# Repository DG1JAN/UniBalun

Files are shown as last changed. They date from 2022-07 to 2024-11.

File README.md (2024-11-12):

# UniBalun
a PCB for a lightweight qrp (maximum 10W SSB & CW or 5W on FT8) 1:49 UnUn (also 1:9,1:64,... possible) or Balun (1:1, 1:4)

Update to Rev. 1.2 with some minor changes (bigger Pads for the Capaciator and updated labeling)

German speaking Hams will now find a new PDF with build instructions (Bauanleitung) in the repo: https://github.com/DG1JAN/UniBalun/blob/main/Bauanleitung_UniBalun.pdf

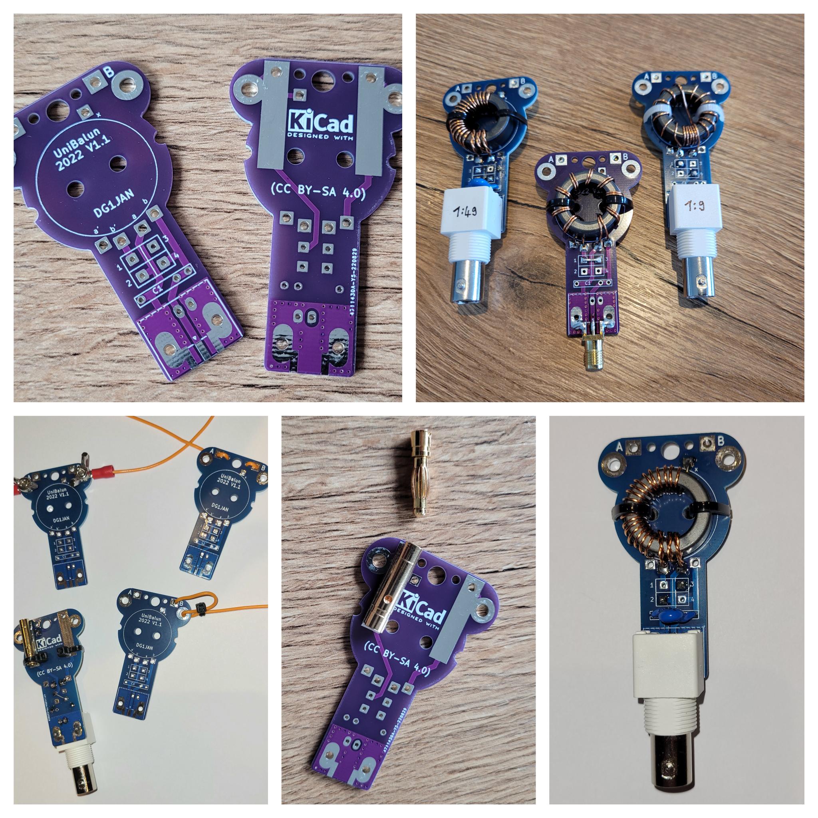
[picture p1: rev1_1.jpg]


Depending on the winding of the toroid, you can use the PCB to create a 1:1 or 1:4 Balun or a 1:49 UnUn.

1:1 Balun: solder a wire jumper between Pad 1 and 3. No capacitor.

1:4 Balun: solder a wire jumper between Pad 1 and 2 and another jumper between Pad 3 and 4. No capacitor.

1:49 Unun: solder a wire-jumper between Pad 1 and 4 on the backside of the PCB (gives better isolation). Solder the capaciator to C1

1:9 Unun: solder a wire-jumper between Pad 1 and 4 on the backside of the PCB (gives better isolation). Solder a Wire on the backside of the PCB between the a' Pad and the GND of the BNC-Plug.

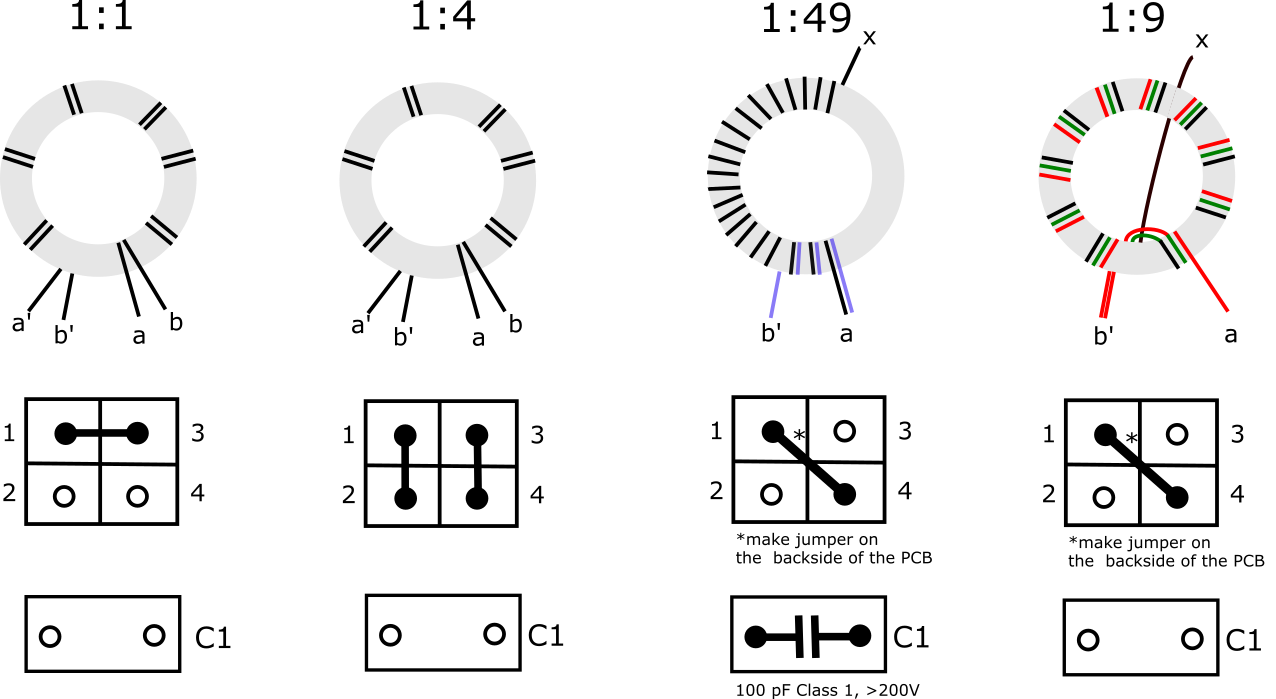
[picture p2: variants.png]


I recommend using "Amidon FT82-43" or "Fair-Rite 5943000601" (100% identical to the Amidon) Cores or the "Würth 74270118" core. The Würth core is a bit better on higer Bands, but should not be used below ~6MHz.

PRO-TIP: For lowest losses, use a FT82-43 with a FT50-43 placed inside the FT82. (they fit nicely together) A Fair-Rite 5943000601 & 5943001101 have even a better match!

Measurements have shown that the best winding radio for 1:49 UnUns on the small FT82-43 sized core is 3-to-21. 

The new revision (>1.1) has a combined footprint for BNC and SMA connectors, so only one version of the PCB is needed (thanks to DL2MAN for the idea).
For BNC connection you can use the Part: Amphenol B6252H7 / Telegärtner J01001A0038 (or similar) <br>
For SMA connection pls use a straight edge mount SMA connector (found some cheap sources at amazon, e.g. : https://www.amazon.de/10-polig-SMA-Buchse-Leiterplattenmontage-Adapter-HF-Steckverbinder-Messing/dp/B07QG2Y9L6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 )

I add two new PADs in revision 1.1 to solder 4mm ("Bana Connector") sockets directly to the PCB. I used this parts: https://www.amazon.de/gp/product/B07VYSN74H/ref=ppx_yo_dt_b_asin_title_o01_s00?ie=UTF8&th=1 

For German or EU-based OM's, I can recommend https://aisler.net/ for PCB manufacturing. You can upload the Kicad file and order the PCBs.<br>
I also have good experience with http://JLCPCB.com from China. You can upload the Gerber Files (as Zip-File) directly to their homepage. delivery time to Germany is ~10 to 14 days.
Manuel (DL2MAN) did a short How-To-Order here on Youtube: https://www.youtube.com/watch?v=1b3oLp7s9gk&t=5s

Pictures from a  1:49 UnUn build:
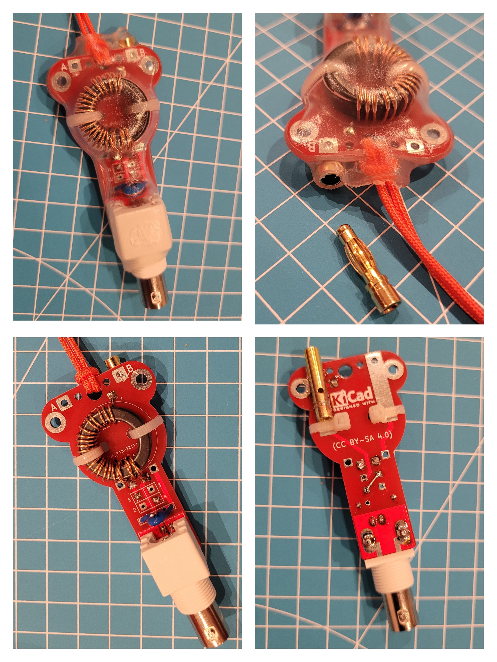
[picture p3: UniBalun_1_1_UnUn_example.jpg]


Pictures from a  1:9 UnUn build:


Here are some YouTube Videos related to the Project:

https://youtu.be/JOxsU2A5xWw?si=09692yh69wdoD_nu

https://youtu.be/WJNUpXuDDTQ?si=r2ZIQGWQCxN_N85m

https://youtu.be/oUK1LmV6amc?si=wLx39TDfT2uAble6

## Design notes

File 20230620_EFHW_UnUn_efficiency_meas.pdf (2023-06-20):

## Comparing the efficiency of Ferrite Toroids for EFHW-Antennas

### DG1JAN, 16. June 2023

Most UnUn’s used for amateur radio End-Fed-Half-Wave (EFHW) Antennas are built on the well know Amidon 43-Material ferrite toroids. Depending on the desired power level these are usually FT50-43, FT82-43, or FT114-43 for QRP or FT140-43, FT240-43 for QRO.

I also build my (qrp) Antennas around Amidon FT82-43 and FT114-43 sized cores without questing too much about the performance of the cores in the past. E.g., my UniBalun project (http://github.com/DG1JAN/Unibalun) is built based on FT82-sized cores.

But after some YouTube Videos from Manuel DL2MAN and Colin MM0OPX, I got curious about the core losses from these “standard” toroids. Colin did measurements with alternative 43-Material ferrite cores and come up with two suggestions for QRP (FairRite 2643625002) and “100W QRO ” (Fair-Rite 2643651002) that are superior to the usual ones.

Already some time ago, I was playing with a “stacked” FT-82-43 / FT50-43 combination. (The FT50 fits nicely inside the FT-82) Unfortunately, I haven’t done any performance measurements till now.

As (IMHO) Amidon toroids are “just” relabeled Fair Ride products (but please enlighten me, if you have detailed information about the relation between Fai Rite and Amidon), I used Fair-Rite products for my tests, as they are available and much Cheaper to source from Digikey as the same cores from Amidon here in Germany.

For the “stacked” FT82/FT50 there is (size-wise) even a better match with the Fair Rite 59430000601 and 5943001101.

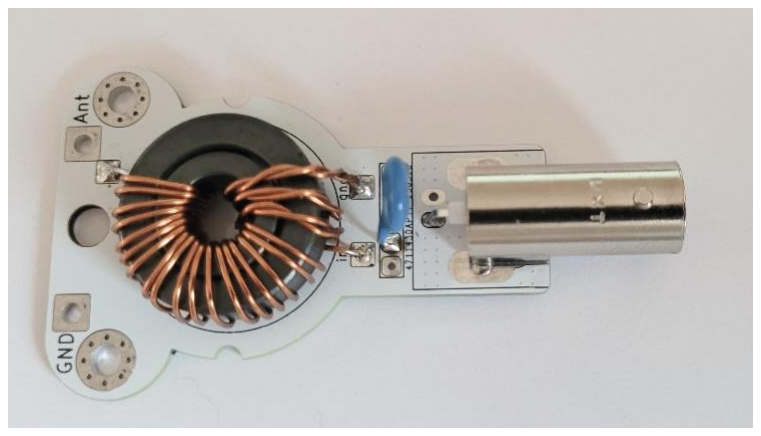
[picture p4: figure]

So, I decide to make some measurements to compare different cores. To have a reference I also include the “QRO” core from MM0OPX .

Instead of doing the Back-to-Back measurements with two “identical” toroids, I decide to go with a measurement setup that uses a load resistor (2400 Ohm – for the 1:49 UnUns). This should lead to better results compared to Back-2-Back, as the flux levels in the two cores are not equal and the losses are not “linear” over the two cores. AI6XG did a nice documentation of his measurements, which at I used as a source.

Following toroids/combinations I have tested:

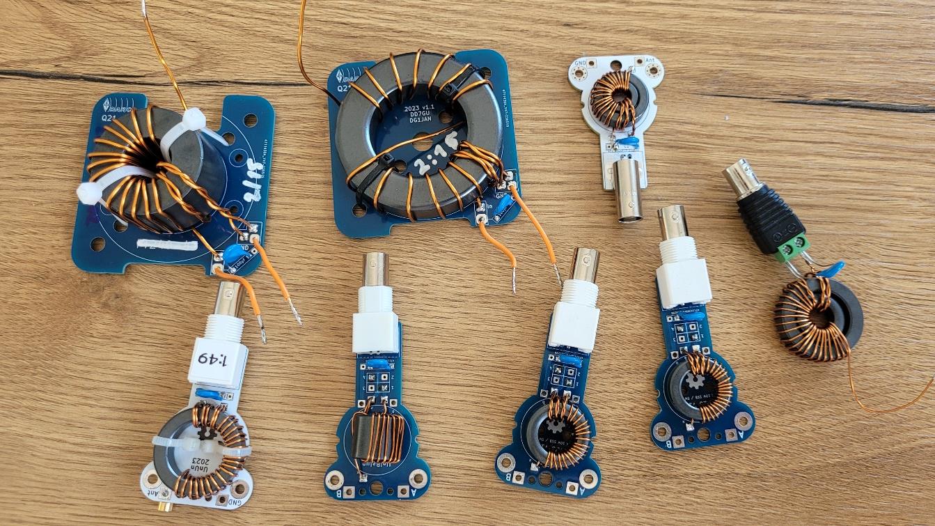
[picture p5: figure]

### Results

For the QRP variants, it could be shown, that the FT82 and FT114-sized cores have average losses of around 20% (80% efficiency). The “stacked” variants (esp. 59430000601 + 5943001101) showed a superior efficiency of around 10% (efficiency across all HF Bands from around 90%). A similar result can be seen for the toroid suggested by MM0OPX (2643625002).

For the “100W” variant the 2643251002 shows even a bigger improvement to the FT240-43. On average the is a 15% higher efficiency. Thanks to Colin for this suggestion!

In the end, it could be discussed, if an improvement in core losses of 10% to 15% makes a real difference in the performance of an EFHW antenna (compare to 6dB per S-Step). But especially for digital modes with typical high-duty cycles, there is (IMHO) a benefit by reducing the core heating due to higher efficiency.

Besides the measured transformer losses here, there are also other losses to consider. E.g. the saturation effects at high flux and especially the temperature-related changes in permeability.

FairRite 2643803802 (FT240-43), 2/15, 100pF FairRite 2643251002 (MM0OPX), 2/15, 100pF FairRite 59430000601 (FT82-43), 3/21, 100pF FairRite 59430000601 + 5943001101, 3/21, 100pF FairRite 5943000501 ("double" FT82-43"), 3/21, 100pF FairRite 2643625002 (MM0OPX), 2/16, 100pF FairRite 5943001001 (FT114-43), 3/21, 100pF FairRite 5943001001 + 2643665902, 3/21, 100pF Amidon FT140-43 , 2/14, 100pF

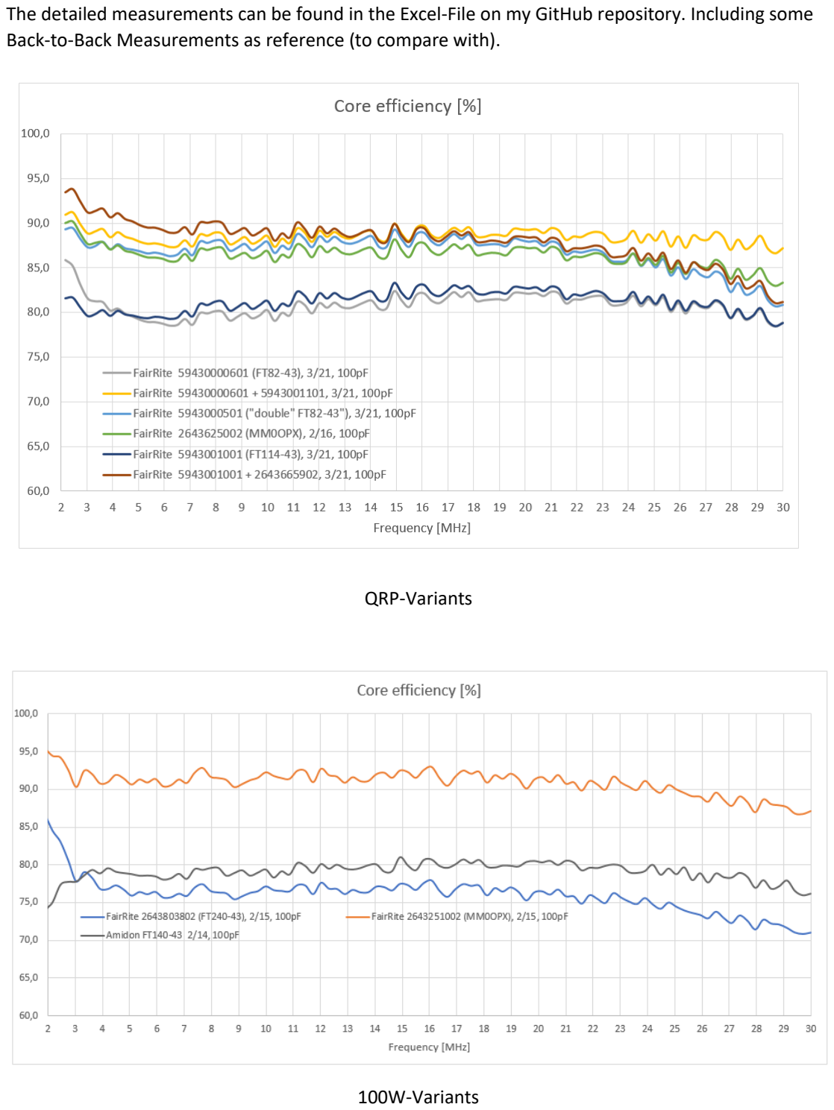
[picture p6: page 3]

The detailed measurements can be found in the Excel-File on my GitHub repository. Including some Back-to-Back Measurements as reference (to compare with).

QRP-Variants

100W-Variants

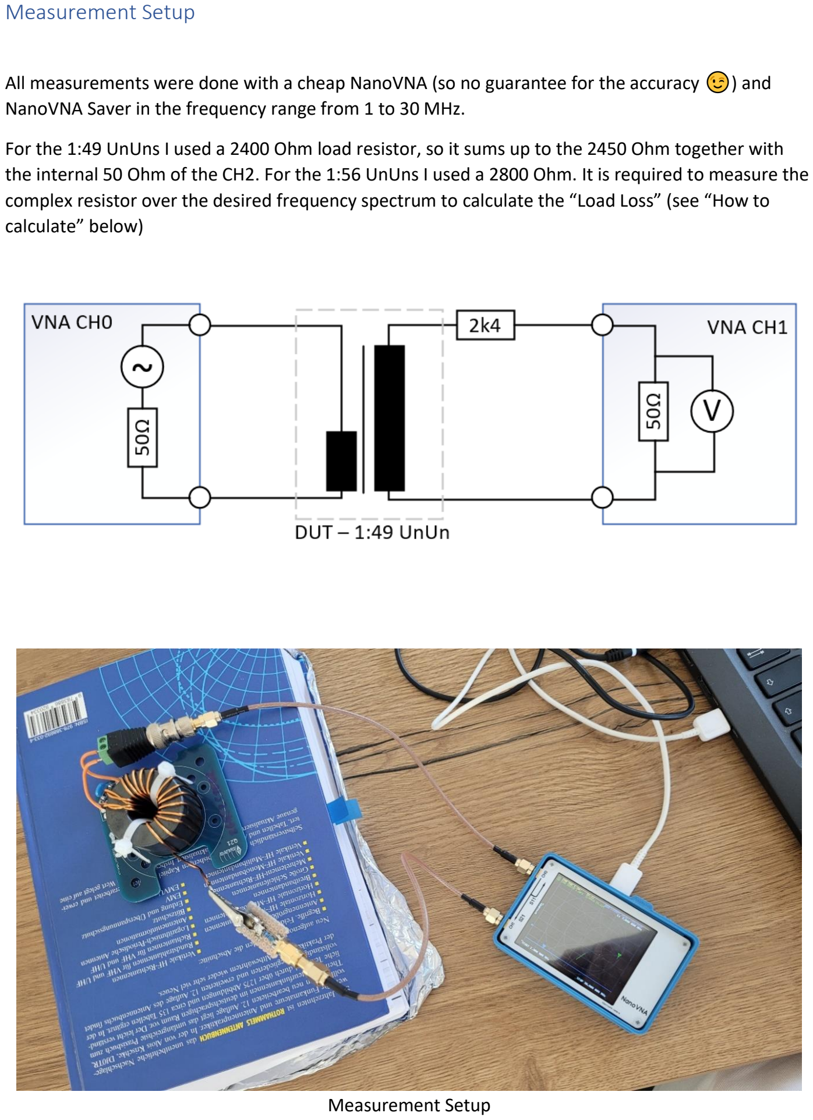
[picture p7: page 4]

### Measurement Setup

All measurements were done with a cheap NanoVNA (so no guarantee for the accuracy ) and NanoVNA Saver in the frequency range from 1 to 30 MHz.

For the 1:49 UnUns I used a 2400 Ohm load resistor, so it sums up to the 2450 Ohm together with the internal 50 Ohm of the CH2. For the 1:56 UnUns I used a 2800 Ohm. It is required to measure the complex resistor over the desired frequency spectrum to calculate the “Load Loss” (see “How to calculate” below)

Measurement Setup

### How to calculate

The total insertion loss of the transformer is calculated by the measured S21 Parameter:

Insertion_Loss[dB] = -20 * log( |21| )

As S21 is a complex value, NanoVNA gives you (in the s2p-file) a real and imaginary part, so you can calculate:

Insertion_Loss[dB] = -20 * log( sqrt ( S21real^2 + S21imag^2 ) )

This Insertion loss is the sum of the Mismatch Loss, the Transformer Loss and the Load Loss (in the Load Resistor). So, we can calculate the core loss by:

Transformer_Loss [dB] = Insertion_Loss[dB] - Mismatch_Loss [dB] – Load_Loss [dB]

The Mismatch Loss is coming from the difference in Impedance on the primary site of the transformer compared to the CH0 Port of the NaoVNA (50Ω+j0 Ω) and calculated from the complex S11 value (given in the s2p-file)

Mismatch_Loss [dB] = 10 * log( 1 - |S11|^2)

With |S11| = sqrt ( S11real^2 + S11imag^2)

As we were required to add a real “Load Resistor” (with capacitive and inductive effects) to match the impedance, we need to measure and calculate the Loss Load. This is done by a series through measurement of the resistor only.

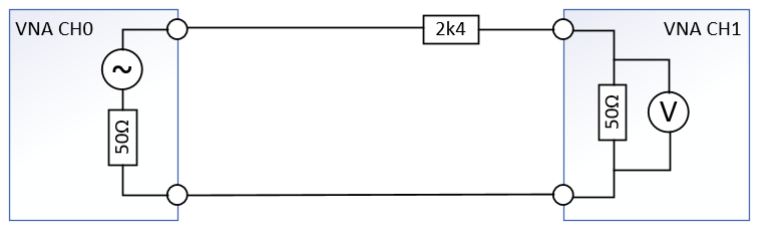
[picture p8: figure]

Load_Loss[dB] = 10 * log ( |S21|^2 / (1-|S11|^2) ))

With |S21| = sqrt ( S21real^2 + S21imag^2) and |S11| = sqrt ( S11real^2 + S11imag^2)

Now we have everything together to calculate the Transformer Loss and the Power Efficiency of the core. (But keep in mind that this is not covering additional losses in practical (esp. QRO) operation with high flux and heating)

Power_Efficency[%] =100 * 10 ^( Transformer_Loss[dB]/10)

BTW: you can also calculate VSWR from the s2p-data:

VSWR = (1 +|S11|) / (1-|S11|)

But please be aware that VSWR is only an indicator, as real EFHW Antennas usually don’t have a perfect real 2450Ω resistance in the resonance points

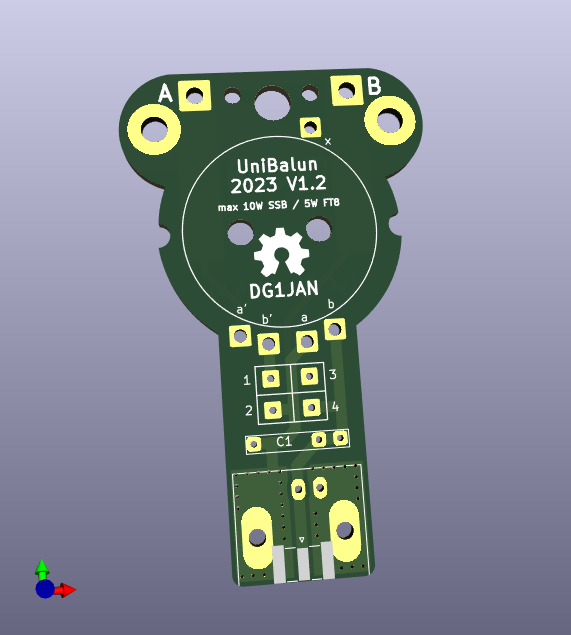
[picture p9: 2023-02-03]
Uni_Balun/UniBalun1.2_3D_Pic1.png

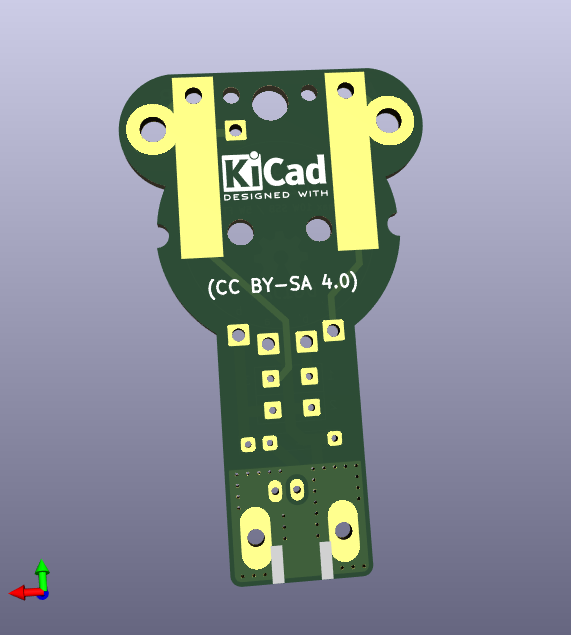
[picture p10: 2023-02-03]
Uni_Balun/UniBalun1.2_3D_Pic2.png

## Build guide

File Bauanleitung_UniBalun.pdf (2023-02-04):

# UniBalun Bauanleitung

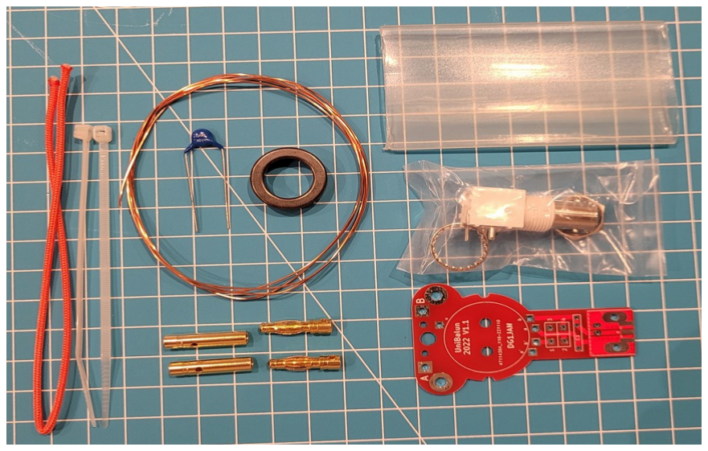
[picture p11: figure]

Materialliste/ BOM

1x Ringkern Amidon FT82-43 oder Fair Rite 5943000601
1x Keramik Kondensator 100pf/1kV
1x Platine UniBalun
1x BNC oder SMA Buchse
1m Kupferlackdraht 0,63mm (oder ähnlich) 2x 4mm Buchse (bei Bedarf)
2x 4mm Stecker (bei Bedarf)
2x Kabelbinder
1x Paracord (bei Bedarf)
1x Schrumpfschlauch 32mm breit (ggf mit Kleber)

Sicherheitshinweis
Diese Bauanleitung richtet sich an lizenzierte Funkamateure, die entsprechend Ihrer Qualifikation über die Gefahren von elektrischem Strom unterrichtet sind, diese einschätzen und einen sicheren Betrieb gewährleisten können.
Die Antenne ist lediglich zur temporären Nutzung bei trockener Witterung (Portabel-Funkbetrieb)
ausgelegt. Maximale Leistung 10W SSB sowie CW bzw. 5W bei FT8 oder ähnlichen Betriebsarten.
Bei Antennen können (auch schon bei geringer Sendeleistungen) hohe HF-Spannungen entstehen. Entsprechende Schutzabstände sowie ein Berührungsschutz sind einzuhalten.
Haftungsausschluss
Es wird vom Ersteller dieser Anleitung keinerlei Haftung für Schäden an Geräten oder Personenschäden übernommen! Weitergehende Ansprüche sind ausgeschlossen.

Für Schäden, die direkt, indirekt oder Folgeschäden, die aus dem Nachbau resultieren, wird keinerlei Haftung übernommen. Dies gilt gleichsam für Schäden, welche durch bestimmungsfremde Nutzung entstehen.

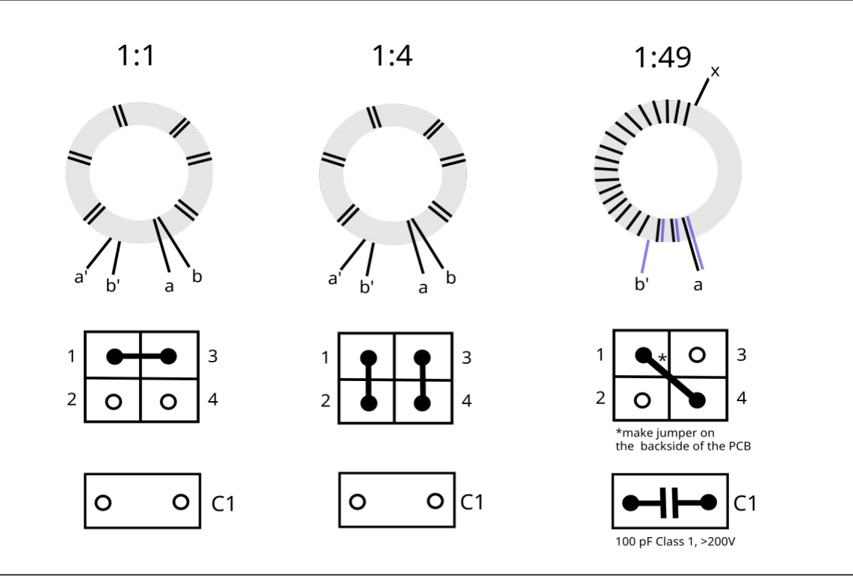
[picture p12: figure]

### Bild 1

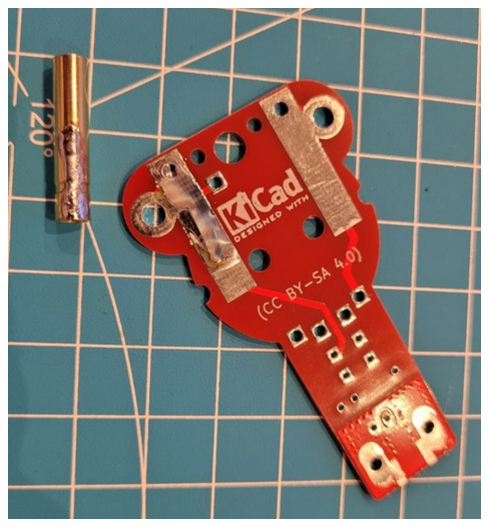
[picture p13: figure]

1) Falls der Anschluss über die 4mm Bananenbuchsen gewünscht ist, sollten diese als erstes aufgelötet werden.

Es kann sinnvoll sein die Buchsen auf der Platine 5mm über den Rand überstehen zu lassen. Damit kann dann ggf. später der Schrumpfschlauch besser abdichten.

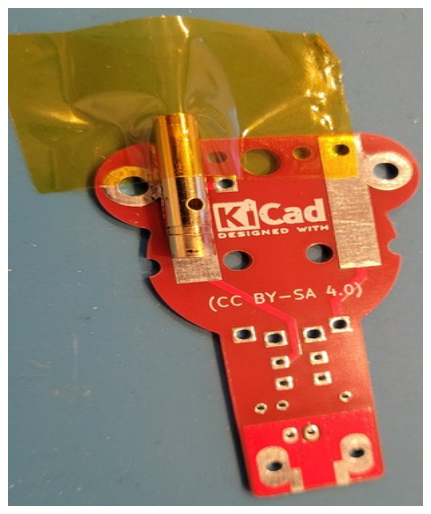
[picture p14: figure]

1.a) Für eine 1:49 EFHW nur die Buchse an Seite B anlöten.

Tipp: Am besten lassen sich die Buchsen mit einem Heißluftlötkolben und SMD-Lötpaste auflöten. Alternativ kann man auch die Bauteile Vorverzinnen und mit Kapton-Tape oder einer Zange/Pinzette beim Auflöten fixieren.

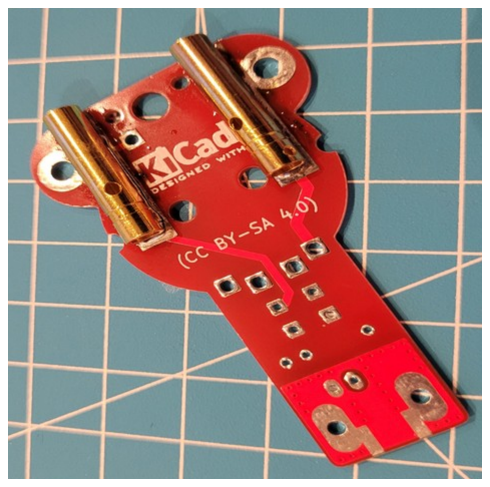
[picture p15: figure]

1.b) Für eine Dipol Konfiguration (1:1, 1:4) beide Buchsen anlöten, sofern keine andere Befestigungsart gewählt wird.

2) Wickeln des Ringkerns

Wickelschema nach Bild 1:

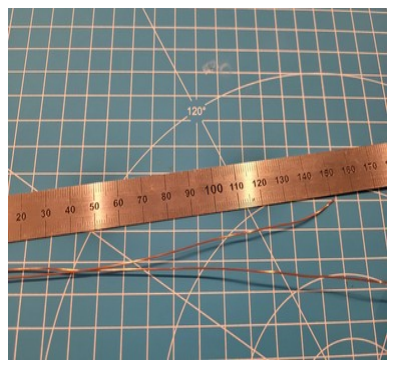
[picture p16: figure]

2.a) Für einen 1:49 UnUn den Kupferlackdraht an einem Ende um etwa 15 cm nach hinten biegen und die zwei Drähte dann leicht verzwirbeln.

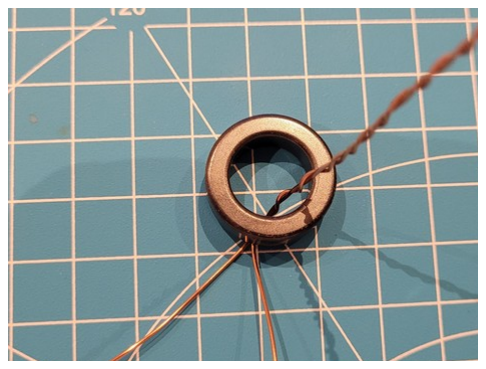
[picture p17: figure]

Von der Mitte an zuerst die Primärwicklung (nach rechts) wickeln.

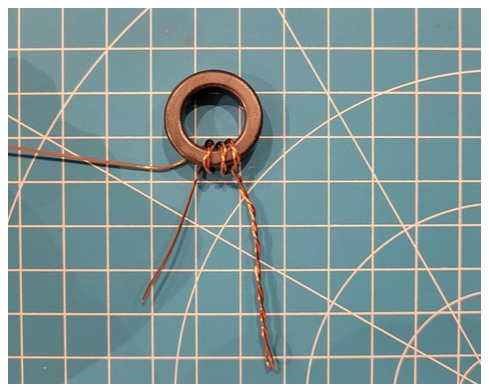
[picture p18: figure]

Mit den verzwirbelten Drähten müssen drei Wicklungen ausgeführt werden.

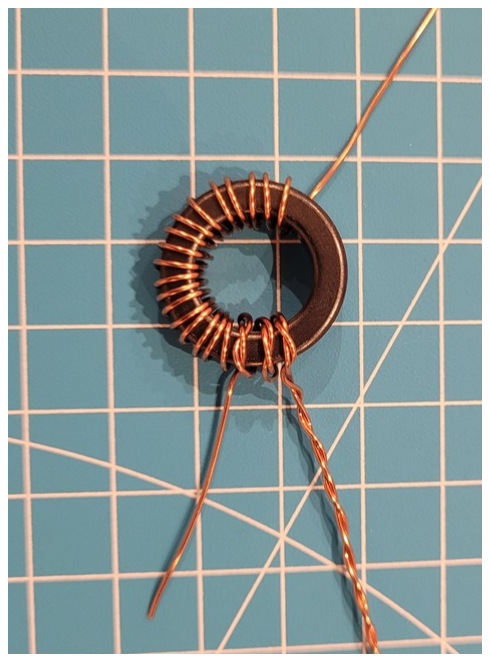
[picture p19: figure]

Danach mit dem langen Drahtende weitere 18 Windungen nach links wickeln. Das Windungsverhältnis ist damit insgesamt 3-zu-21, welches einer Impedanztransformation von 1:49 entspricht.

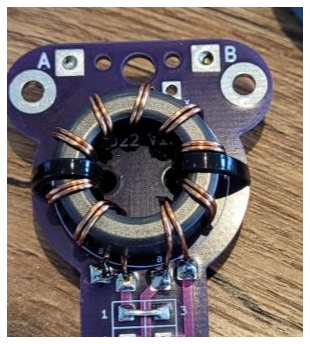
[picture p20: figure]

2.a) Für einen 1:1 oder 1:4 Balun den Kupferdraht halbieren und 9 (oder mehr) Bifilar-Windungen wickelt. Dabei darauf achten, dass sich die Drähte nicht überkreuzen und Parallel aneinander liegen.

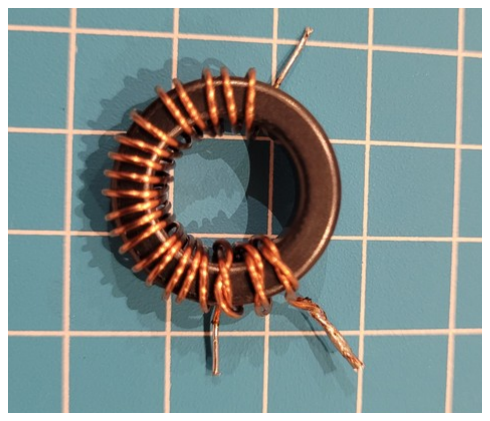
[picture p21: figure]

3) Die Enden des Kupferlackdrahts jeweils auf etwa 1,5cm einkürzen und verzinnen. Tipp: zuvor den Schutzlack durch leichtes „kratzen“ (Elektronikseitenschneider, Messer, etc.) im Bereich der Lötstelle entfernen.

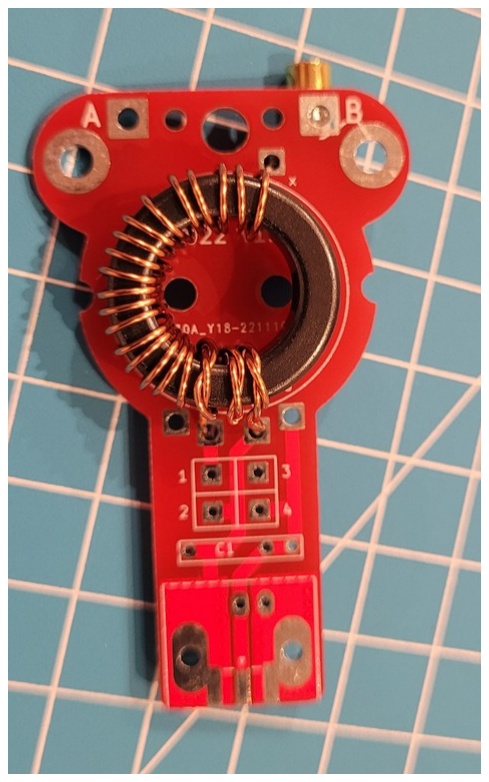
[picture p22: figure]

4) Einlöten des Ringkerns. Anschluss entsprechend Bild 1. (hier 1:49 UnUn als Beispiel) Tipp: Bei dem 1:49 UnUn unbedingt darauf achten, dass die mittleren Anschlüsse (b’ und a) genutzt werden!

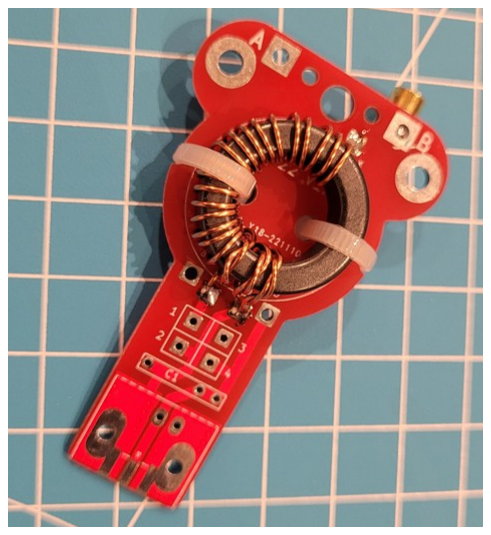
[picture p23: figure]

5) Befestigen des Ringkerns mit den zwei Kabelbindern.

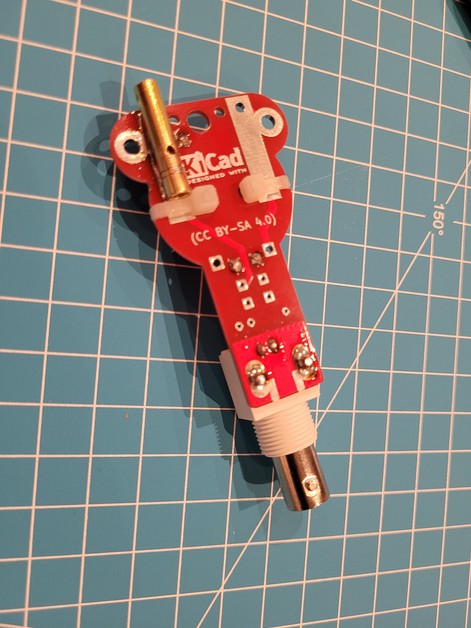
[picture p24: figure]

6) Einlöten der BNC Buchse (alternativ kann auch eine „edge-Mount“ SMA-Buchse verwendet werden.)

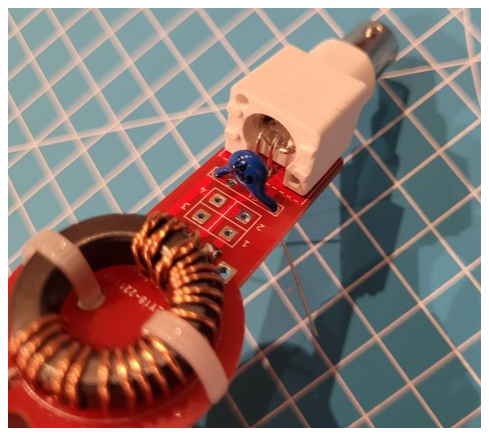
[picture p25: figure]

7) Für den 1:49 UnUn, den 100pF Kondensator einlöten.

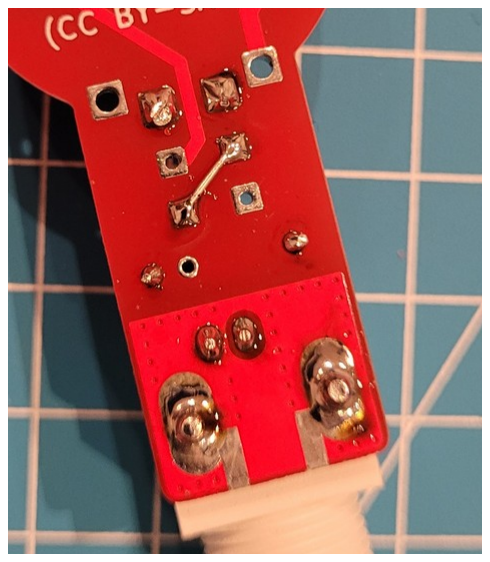
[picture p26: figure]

8) Drahtbrücke(n) nach Bild1 einlöten: 1:1 1:4 1:49 *Für den 1:49 UnUn wird empfohlen, die Drahtbrücke auf der Rückseite der Platine zu machen. (siehe Bild rechts) Hierzu können die abgeschnittenen Anschlussdrähte des Kondensators genutzt werden.

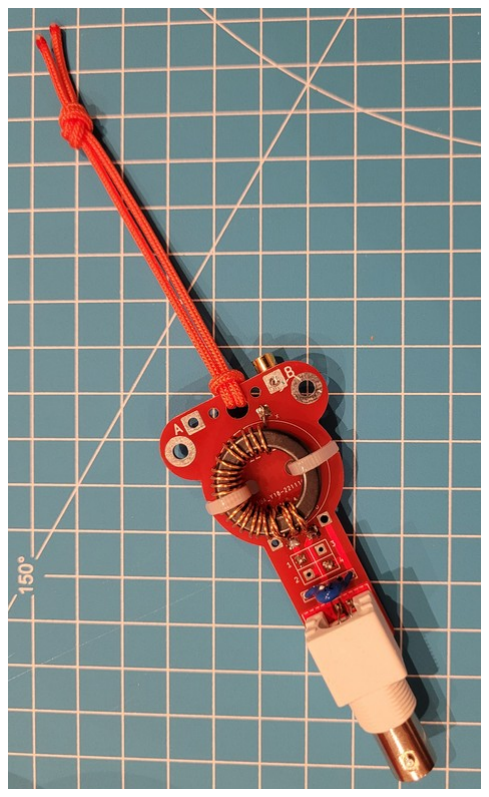
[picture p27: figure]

9) Seilschlaufe (sofern gewünscht) befestigen

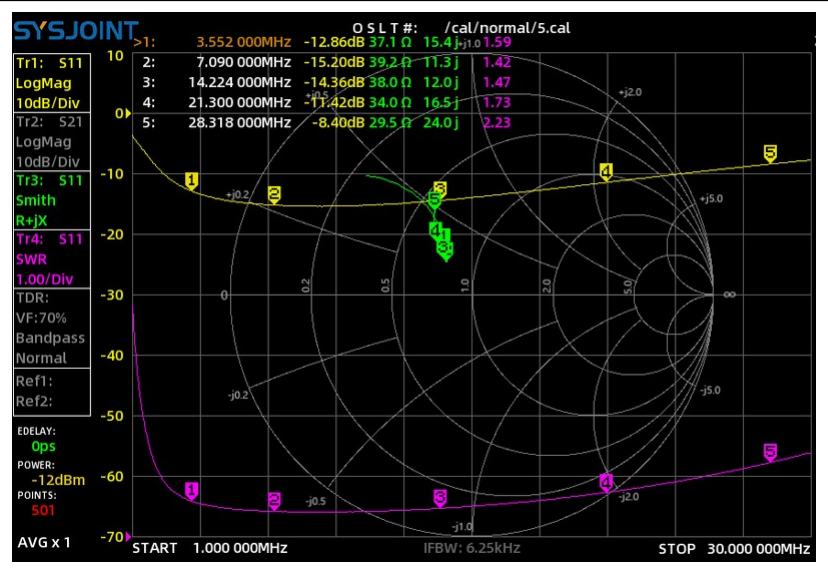
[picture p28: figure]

10) Funktionsprüfung durchführen.

Tip: Idealerweise mit einem VNA den Balun/UnUn auf Funktion prüfen. Dazu die Antennenseite mit entsprechendem Widerstand abschließen und VSWR bzw. S11 messen.

(Beispiel für einen 1:49 UnUn mit 2450Ohm Abschlusswiderstand an einem VNA im Bild rechts)

Abschlusswiderstand:
- für 1:49 UnUn → 2450 Ohm von Anschluss B nach Masse
- für 1:1 Balun → 50 Ohm von Anschluss A zu Anschluss B
- für 1:4 Balun → 200 Ohm von Anschluss A zu Anschluss B

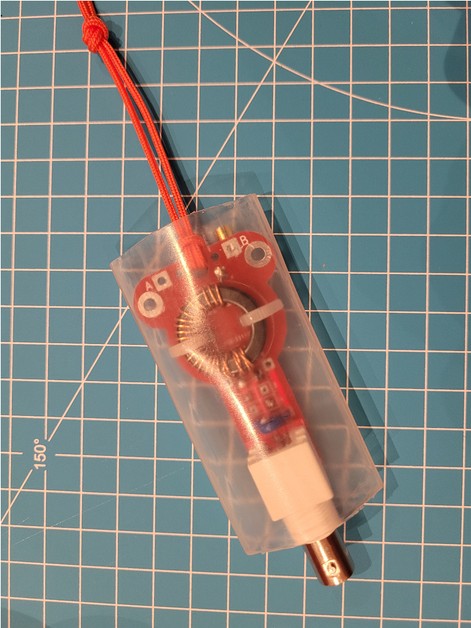
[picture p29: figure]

10) Nach erfolgreicher Funktionsprüfung (bei Bedarf) die Platine mit Schrumpfschlauch einschweißen.

### Wenn der Schrumpfschlauch mit einer Klebeschicht versehen ist, lässt dieser sich nach dem Verschweißen so gut wie nicht mehr entfernen !!!

Tipp: Den Schrumpfschlauch an der oberen Seite (bei den Antennenanschlüssen) ein wenig überstehen lassen. Im heißen Zustand kann das Ende dann zusammengedrückt werden und der Kleber schließt alles Wasserdicht ab. Mit einem Messer oder Elektronikseitenschneider können die 4mm Bananenbuchsen nach dem Auskühlen dann wieder freigelegt werden.

9) Befestigen des Antennendrahts nach Wahl ;-)

### Viel Spaß und Erfolg beim Nachbau!

### 55 & 73 de Jan, DG1JAN

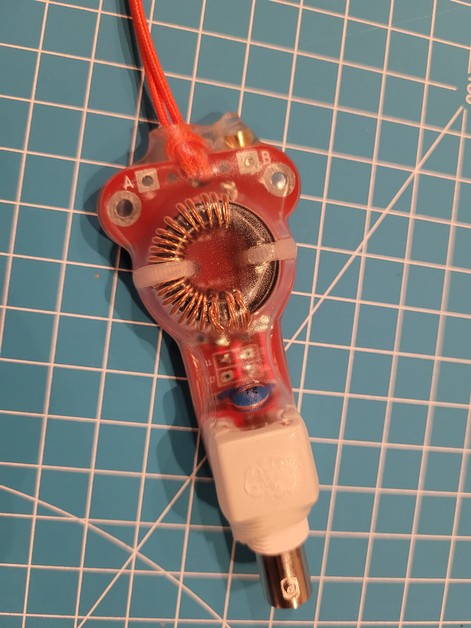
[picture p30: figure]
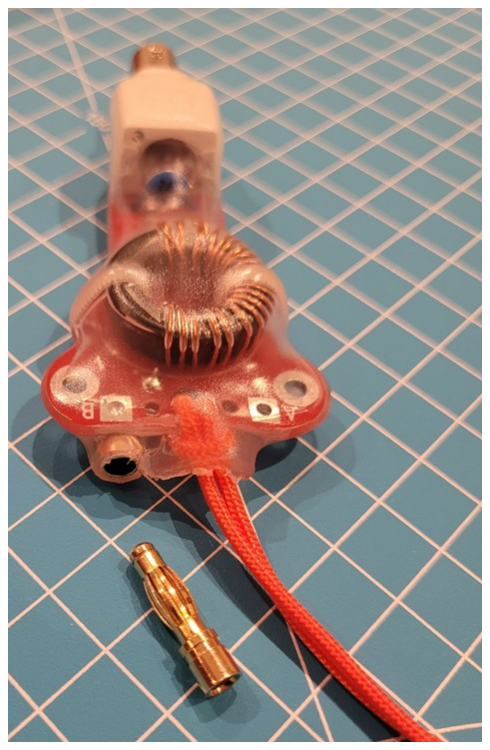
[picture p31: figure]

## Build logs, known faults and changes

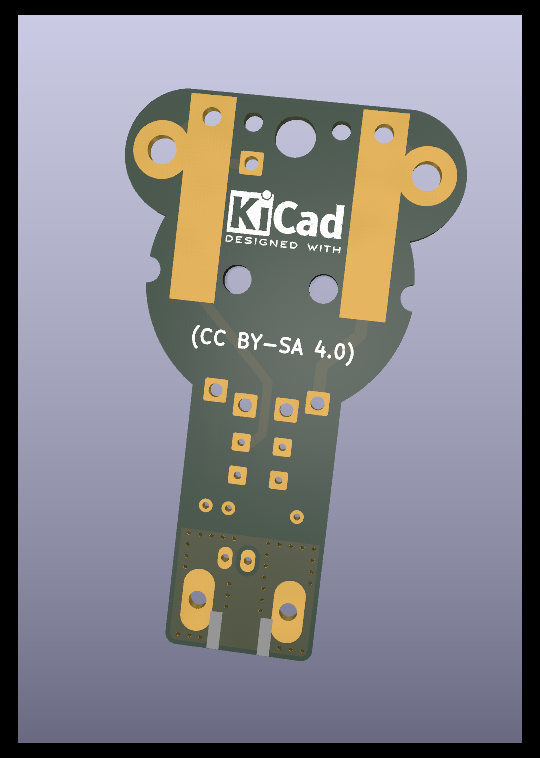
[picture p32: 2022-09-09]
history/UniBalun_1.1/pic_3d_back.png

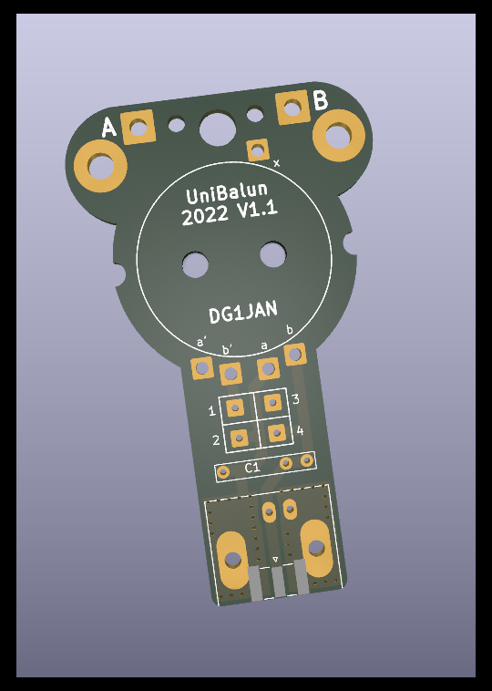
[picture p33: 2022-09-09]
history/UniBalun_1.1/pic_3d_front.png

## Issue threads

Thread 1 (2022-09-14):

BNC male plug version

dl1hbt, 2022-09-14:
Jan, I am a big fan of less cable whereever possible. Do you think it might be possible to change the PCB design to be able to use a BNC male plug 90 deg angle as well? I have found this one on amazon: https://amzn.eu/d/83ZCG39 but did not order any by now. Maybe it fits without the need to change the PCB design...vy73/55, Tom (DL1HBT)

dl1hbt, 2022-09-16:
Hi Jan, I have ordered five BNC plugs for PCB installation via amazon. I expect them to arrive from China within the next two weeks. I will check the footage and give feedback on whether it works with or without the need to edit the PCB design. vy73/55, Tom

dl1hbt, 2022-09-16:
Jan, that´s perfect...thanks for your actions taken. My address is up-to-date, I am looking forward to receiving the PCB and will reply as soon as I have received the BNC plugs from China. Thanks also for your hint oncerning the necessity for a counterpoise! vy73/55, Tom

dl1hbt, 2022-09-17:
Jan, PCB v1.1 arrived today...thanks!

dl1hbt, 2022-09-23:
Jan, received the BY-BNC 90 deg angle plug for PCB mountage yesterday. I will send you one sample, prbably you might want to check, if the PCB design can be modified easily and a mount point for a counterpoise can be marked on the board. vy73/55, Tom

DG1JAN, 2022-09-23:
Hi Tom, thanks. I will have a look and will do a  "special" version that support your connector. In this case I think it makes sense to remove the posibillity for BalUn usage of the PCB (as it will be attached to radio directlý, the Dipol configuration will make no sense anyhow.
Then I can use the "A" antenna connector for GND/Counterpoise and "B" will be for the Antenna.

dl1hbt, 2022-09-25:
Hi Jan, yes...maybe it is clever to seperate the PCBs capability to handle Balun _and_ UnUn...
Back from SOTA in DM/TH and DM/HE, Tom

DG1JAN, 2022-09-28:
Thanks Tom,

part has arrived :-) The Footprint is not compatible with the SMA-connector, so I made a new Version (only 1:49) with your Part.
All Files (KiCad and  Gerber) can be found here: https://github.com/DG1JAN/AntennaPlayground/tree/main/DL1HBT_UnUn

Closed 2022-09-28.

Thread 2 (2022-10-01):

1:49 Capacitor?

Mkpowell2, 2022-10-01:
I apologize if I missed it, but could you please clarify which capacitor you recommend for the 1:49 version? I am trying to build this amazing project but don't know which capacitor to use.

A part number would be awesome if you have one handy as I am not familiar with electrical engineering. Thank you!

Myles

DG1JAN, 2022-10-02:
Hello Myles,

thanks a lot for the nice words and your question.
You can use any 100pF Ceramic or Silver Mica capacitor that has a voltage rating >200V (even 100V would be Ok for qrp, but I like to have some margin).

I don't know, where you from, and what distributor you prefer.
Here are some sources as example:
https://www.reichelt.de/it/de/keramik-kondensator-100-pf-3-kv-85-c-vis-hcz101kbcdf0-p247584.html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

https://www.digikey.de/de/products/detail/tubedepot/CP-SM-100-500V/10489633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

you can also have look on Amazon. search for "100pf silver mica capacitor"

Regarding the shrink tube, you can use any product, that is wider than 40mm. can be found e.g. on Amazon as well.

BR, vy 73
Jan

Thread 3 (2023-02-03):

Aisler.net shows warning on shortened pads

db6edr, 2023-02-03:
Hi Jan,

I've just uploaded the UnUn_BNC/UnUn_BNC.kicad_pcb to Aisler.net. Their board inspector gives a remark on some shortened pads. As I'm not used to creating / fabricating PCBs: is that as expected? Or does this require fixing?

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

73 de Dirk DB6EDR

DG1JAN, 2023-02-03:
Hello Dirk,

Thanks for the hint! This is a non functional issue, due to my manual editing of the PCB (out of the UniBalun File).
Didn't checked it, because I ordered at JLCPB using gerber files.

I have updated the Net classes in the pcb file, so the Error from Aisler.net should be gone.

73 de Jan, DG1JAN

db6edr, 2023-02-03:
Just checked, the error is gone.

Thanks!

Closed 2023-02-03.

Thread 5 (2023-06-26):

Query re efficency spreadsheet - FairRite 5943000601 + 5943001101

virtual812, 2023-06-26:
If I understand correctly you've found some significant efficiency with this combo.

I'm looking to replicate your results, it would seem you had the smaller toroid sitting inside the larger one, is this correct?
Would this also marginally increase power handling? say 20W SSB / 10W FT8?

Have you any advice for size of copper wire?
Sounds in theory that things might get tight inside the 7.9mm ID of the smaller toroid.

Also any thoughts on good cores for 1:1 and 4:1 baluns running ~ 80M to 10M bands?

DG1JAN, 2023-06-27:
yes, I think the combination of the FairRite 5943000601 + 5943001101 (or Amidon FT82-43 + FT50-43) will bring a slightly improvement in efficiency according my measurements. I would really appreciate if you (or other OMs) could validate this.

Do to the lower core losses and a bit higher mass of the combined toroids, I guess also the power handling will improve. But I haven't done any measurements yet. I only used a 1:49 with this configuration for 20W portable operation in SSB. I didn't recognize any warming (ambient temp 27°C) during this. (Of course SSB was on a very low duty cycle)

As copper wire I was using 0,63mm, as you can se in the picture in the PDF its tight, but just ok with the 3-to-21 winding.

I haven't done much testing for Baluns, yet. From the efficiency point, the core its much less critical IMHO, as only the common mode current is creating flux. For smal dipols (linked Inv-V) I have used Amidon F82-43 (or FairRite 5943000601) and Würth 74270118. But don't expect to much common mode rejection below the 20m Band with the small cores. (for 14 to 30Mhz i measured ~20 - 30 dB, but only 13dB on 40m and 7dB on 80m)

virtual812, 2023-06-30:
Thanks Jan, will have a go.
Not done a lot of building & testing before, will read up on how to test.
I think i've seen a kind of back to back test done by you and/or DL2MAN.
Weather is beginning to improve here in Australia so hopefully will be outdoors and on air soon.
QRM at home is terrible!

virtual812, 2023-07-06:
PCBs ordered, Toroids ordered, struggling to find 0.63 Enameled Copper Wire.
I have 1.0mm and 0.8mm on hand.
I can buy 0.56mm and 0.71mm
Looking at capacitors also, the PDF mentions class 1
My RF knowledge is still elementary, but I'm aware capacitor types matter.

I have some of these in 100pF...
https://www.minikits.com.au/Mica-Series

I'm also looking at buying these - Dielectric Characteristic SL...
https://au.element14.com/tdk/cc45sl3ad101jyvna/disc-capacitor-100pf-1kv-radial/dp/3651151

and / or these  - Dielectric Characteristic	C0G / NP0...
https://au.element14.com/tdk/fg28c0g2e101jnt06/cap-100pf-250v-mlcc-radial/dp/3416508

I'll collect up all the parts and read up on how to test.
My understanding is that testing works best with 2 matching units back to back on a VNA.
It's a crude instrument i think, but i have a nanoVNA that i could try.

I'm also looking at building your balun test tool.
At up to 60MHz do resistor types matter?
Looking at metal film, wire wound and ceramic.
I recall reading somewhere that some kinds of resistors add inductance, the wire wound probably and maybe the metal film?
Any thoughts on that?

I'd be happy to test and share my results.

DG1JAN, 2023-07-23:
I think 0.56mm is a good choice for the combined cores.

The Mica caps are fine. I usually use TDK  CC45SL3FD101JYVNA (e.g. from DigiKey)

For testing it is important to use low inductance resistors like metal-oxide. In general I would not recommend using my "Balun Test tool" for >30MHz. In general its better to use single resistors with very shorts leads (as short as possible).

schornhe, 2023-07-25:
To which spreadsheet are you referring. Can you please provide a link?

virtual812, 2023-07-26:
> To which spreadsheet are you referring? Can you please provide a link?

It's in the repository.
https://github.com/DG1JAN/UniBalun/blob/main/20230620_UnUn_Efficency_Meas.xlsx

virtual812, 2023-10-01:
Hi Jan, finally getting around to this.
I'm expecting the toroids to arrive any day.
Just had some questions about the testing method.
I have both a nanoVNA and a TinySA, i also have your balun test tool.
I see a rough idea about how to test here.
Is this similar to the method you used?
I'm still learning a few things.
I don't have it with me currently, but i guess there is a mode where the VNA can output a signal and measure loss on it's incoming port.
Any info you could share on how you tested would be appreciated.

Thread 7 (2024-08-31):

wiring for 9:1 unun

benmarwick, 2024-08-31:
Hi Jan,

Thank you so much for making available the plans for these very versatile boards. I am attempting to make the 9:1 unun by following the image here https://github.com/DG1JAN/UniBalun/blob/main/UniBalun_1to9_example.jpg and just want to check I have the wiring correct.

Here's the description of my wiring:
-  start of wire 1 joined to end of wire 2.
-  start of wire 2 joined to end of wire 3, both soldered to b', which goes to the coax centre pin via a bridge between 1 and 4 on the back of the PCB
- start of wire 3 soldered to a, which goes to coax shield and counterpoise attachment A, via a bridge on the back of the PCB
- end of wire 1 soldered to x, which is antenna attachment B

And here's a simple schematic:

```
w1-start -----------|
w2-start ------|    |
w3-start ------>---->----- a - coax shield & cp via bridge to a'
               |    |
               |    |
w1-end -------->---->----- x - B - antenna
w2-end -------->----|
w3-end --------|
               |
               b'
               |
          1 bridge to 4
               |
            coax pin

```

Does that look right to you?

Thank you so much,

Ben

DG1JAN, 2024-09-12:
Hello Ben,

I'm sorry its a bit hard for me to read the ASCII Schematic. Please have a look to this document
https://github.com/DG1JAN/UniBalun/blob/main/Bauanleitung_UniBalun_als_1zu9.pdf

Unfortunately I made this Instruction only in German yet, but from the pictures I guess its pretty easy to understand how I did the wiring.

best 73 de Jan

benmarwick, 2024-09-13:
Thank you for your reply, yes I was looking at this image from your PDF and found it confusing to understand what to do with ends of the wires.

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

I see red, green and black wires on the left, and the other ends of those wires on the right. But for the ends of the wires in the PDF I only see two red and one black. It is not clear what to do with the two green ends, and the other black end.

Is it the same as this diagram from [vk6ysf.com](https://vk6ysf.com/unun_9-1.htm)

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

Thank you so much

DG1JAN, 2024-09-15:
yes, its the same. sorry for confusing. maybe its also because I dont have wire "ends". I use to wound the UnUn in one turn. Means, making a tab after the first coil and then winding two more rounds. (as you can see in the photos of the pdf)

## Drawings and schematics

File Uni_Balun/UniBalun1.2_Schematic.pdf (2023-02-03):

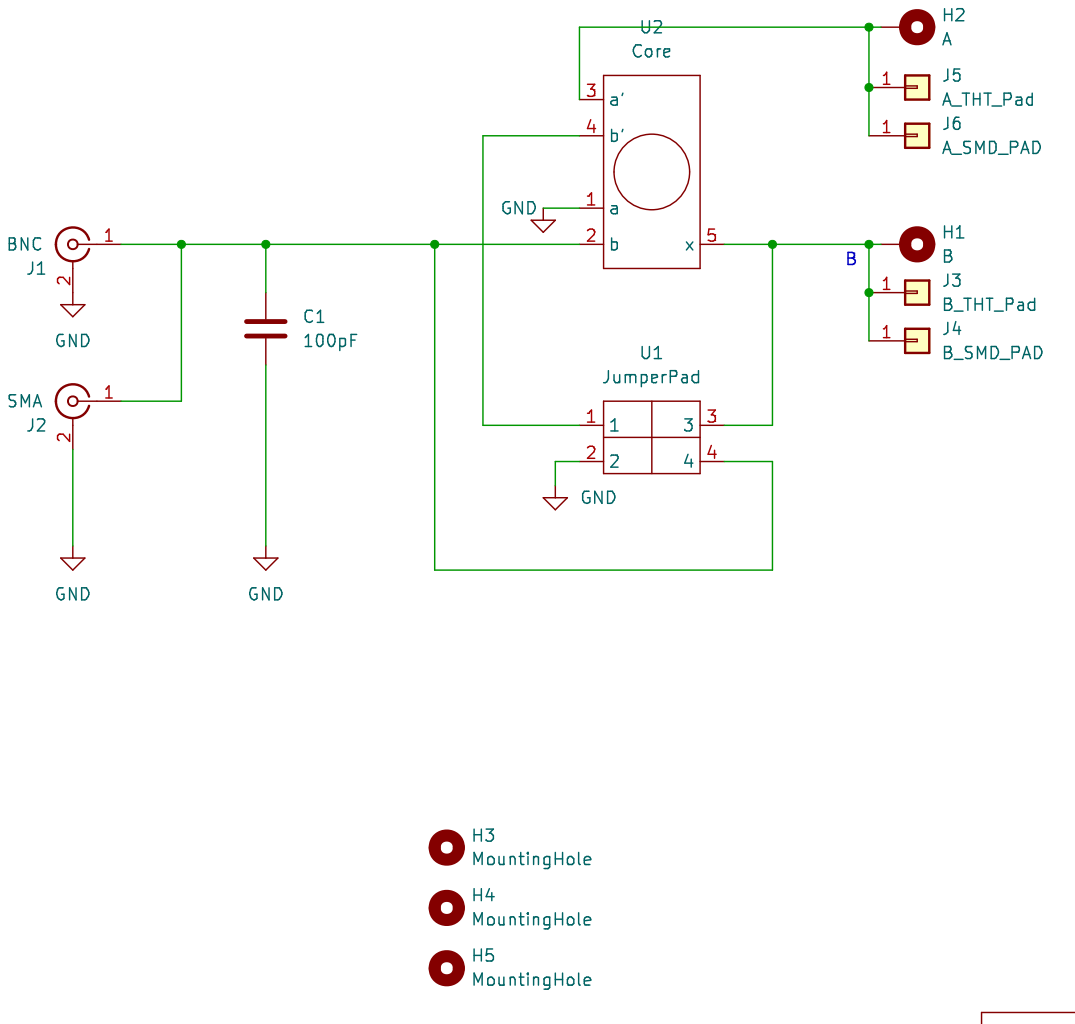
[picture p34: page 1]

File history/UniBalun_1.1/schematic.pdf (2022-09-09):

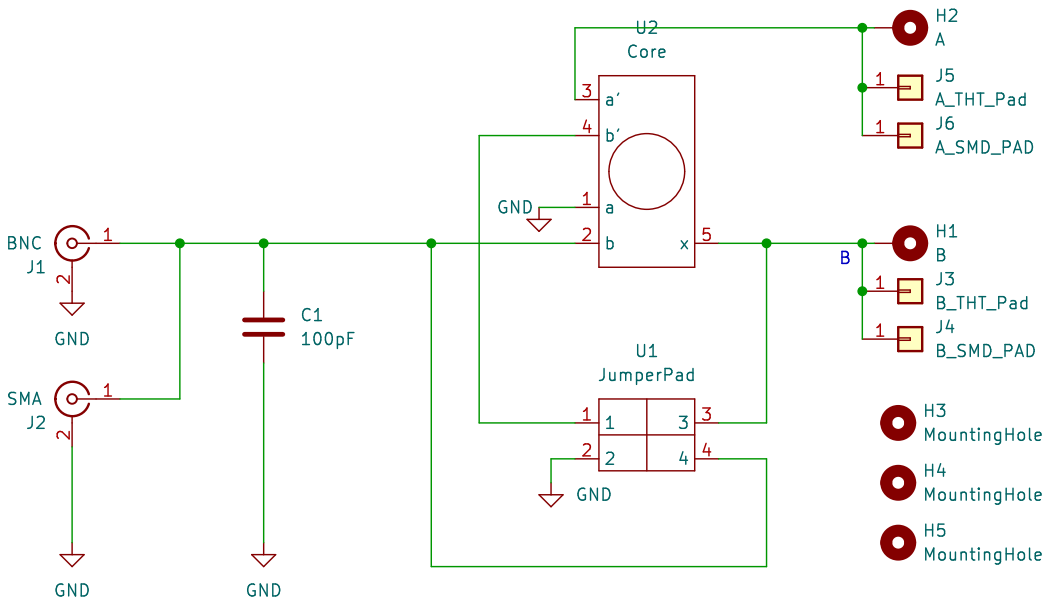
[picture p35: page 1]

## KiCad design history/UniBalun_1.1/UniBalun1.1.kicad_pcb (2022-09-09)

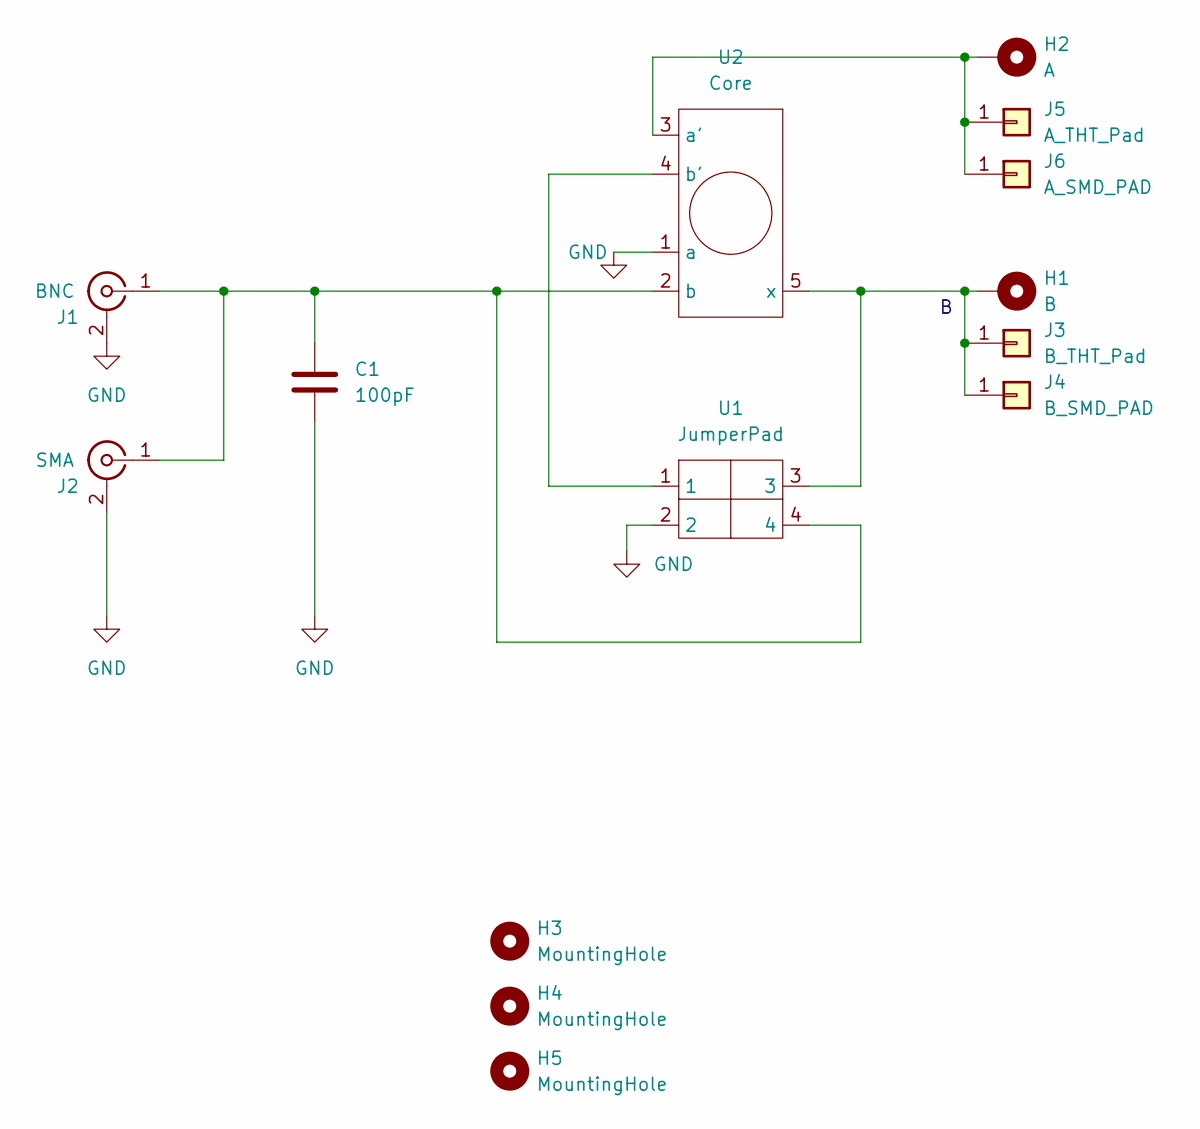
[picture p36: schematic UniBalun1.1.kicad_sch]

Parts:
C1: 100pF; THT_cap
H1: B; MountingHole_3.2mm_M3_Pad
H2: A; MountingHole_3.2mm_M3_Pad
H3, H4: MountingHole; MountingHole_2.1mm
H5: MountingHole; MountingHole_4.5mm
J1: BNC; BNC_Amphenol_B6252HB-NPP3G-50_Horizontal
J2: SMA; SMA_Samtec_SMA-J-P-X-ST-EM1_EdgeMount
J3: B_THT_Pad; SolderWire-1.5sqmm_1x01_D1.7mm_OD3.9mm
J4: B_SMD_PAD; 4mmJack
J5: A_THT_Pad; SolderWire-1.5sqmm_1x01_D1.7mm_OD3.9mm
J6: A_SMD_PAD; 4mmJack
U1: JumperPad; Jumper
U2: Core; FT82_Balun

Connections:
GND: C1.2, J1.2 (Ext), J2.2 (Ext), U1.2, U2.1 (a)
unnamed: C1.1, J1.1 (In), J2.1 (In), U1.4, U2.2 (b)
unnamed: H1.1, J3.1, J4.1, U1.3, U2.5 (x)
unnamed: H2.1, J5.1, J6.1, U2.3 (a')
unnamed: U1.1, U2.4 (b')

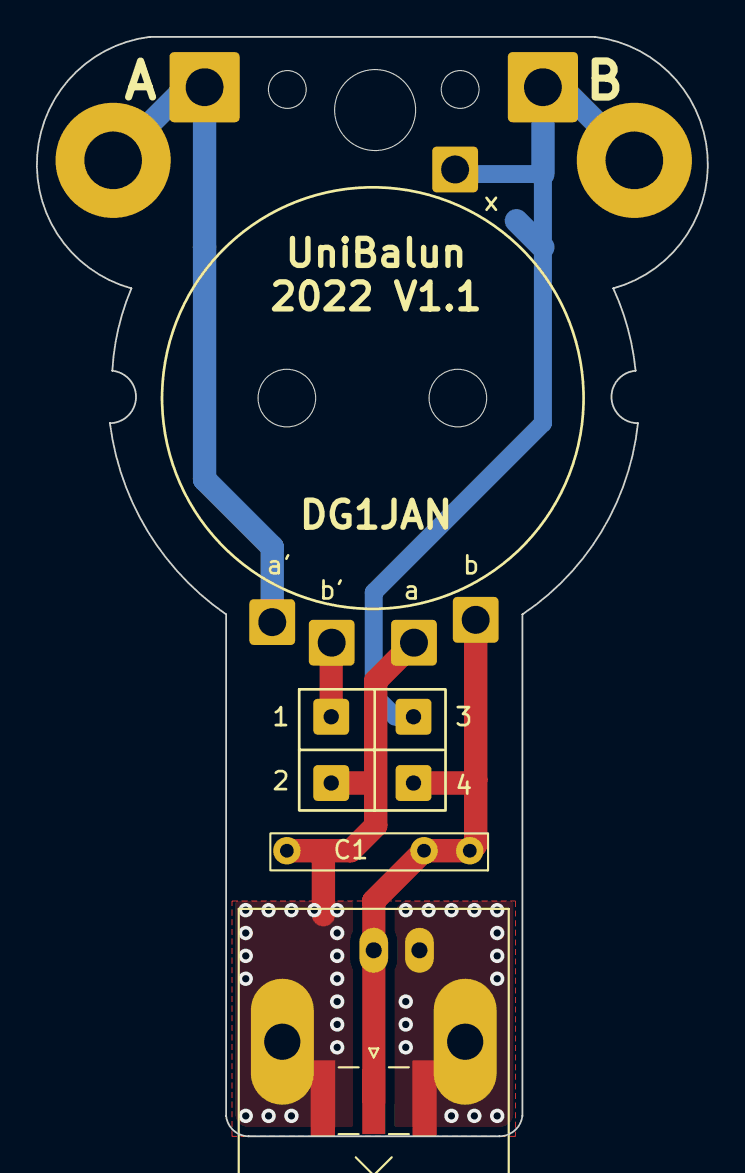
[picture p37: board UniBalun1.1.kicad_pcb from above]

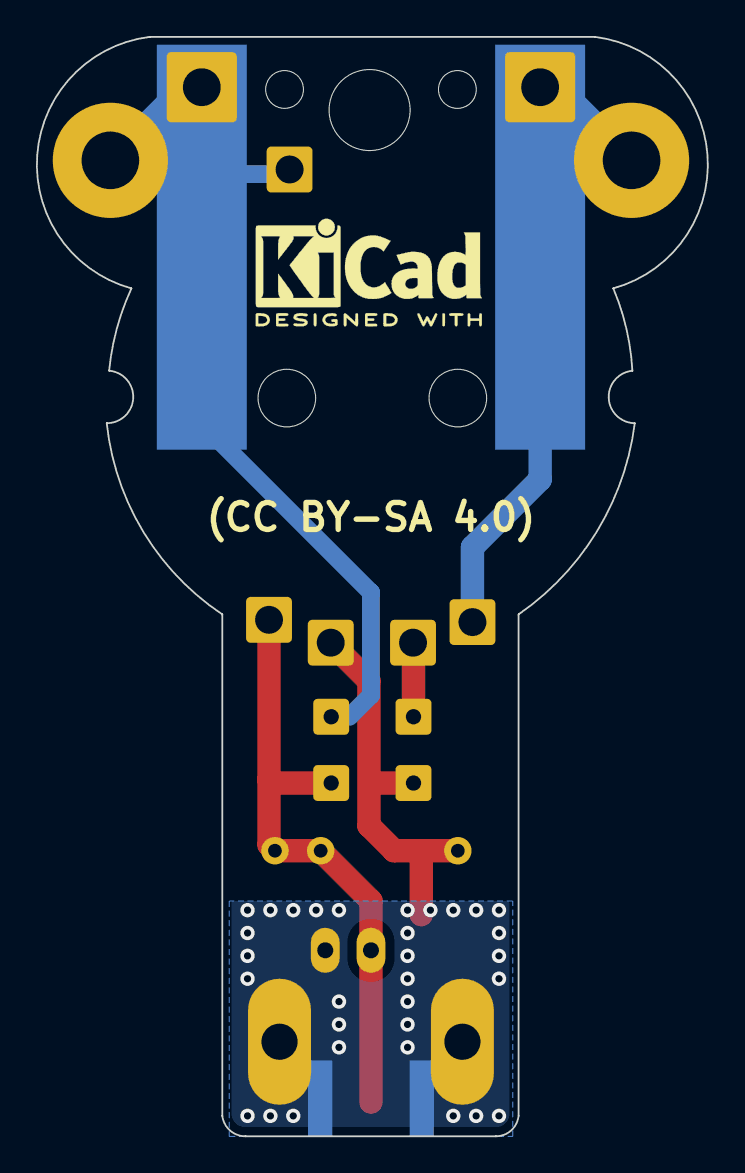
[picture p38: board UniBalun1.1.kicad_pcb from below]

Board: 2 copper layers, 37.3 x 61.1 mm, 14 parts (2 on the bottom side), 5 nets.

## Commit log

2022-07-14 Alternativ Version using a BNC instead of SMA
    [UniBalun_BNC.kicad_pcb]
2022-09-09 update new layout
    update for new version of Layout
    [UniBalun.kicad_pcb, UniBalun_BNC.kicad_pcb]
2022-09-09 update to new revision 1.1
    [UniBalun1.1.kicad_pcb, UniBalun1.1.kicad_sch]
2023-02-03 update to Rev 1.2
    only smal changes
    - bigger Pads for the Capaciator
    - updatetd labeling
    [UniBalun1.1.kicad_pcb, UniBalun1.1.kicad_sch, UniBalun1.2.kicad_pcb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]
2023-02-03 upload gerber files for Rev 1.2
    [UniBalun1.2-B_Cu.gbr, UniBalun1.2-B_Mask.gbr, UniBalun1.2-B_Paste.gbr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]
2023-02-03 add variants of the UniBalun
    CoaxBalun can be use to Build a 1:1 without need for a (Heav) connector
    UnUn_BNC is a Version only for Endfed Antennas and does only support BNC
    [CoaxBalun-B_Cu.gbr, CoaxBalun-B_Mask.gbr, CoaxBalun-B_Paste.gbr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]
2023-02-03 fixed issue with netlist (no functional change, only to prevent DRC Error at Aisler.net)
    [UnUn_BNC.kicad_pcb]
2023-08-31 clean up
    [CoaxBalun-B_Cu.gbr, CoaxBalun-B_Mask.gbr, CoaxBalun-B_Paste.gbr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]
2024-07-15 copy library from v1.1 to current v1.2

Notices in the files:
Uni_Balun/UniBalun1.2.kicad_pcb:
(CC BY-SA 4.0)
